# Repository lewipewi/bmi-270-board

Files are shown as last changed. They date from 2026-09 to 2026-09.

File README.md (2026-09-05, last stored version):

# bmi-270 board

Compact wireless 6-axis motion sensor board. Single-cell LiPo or USB powered,
with USB-serial for flashing and debug. Part of a larger project aimed at playing fighting games using the body.

## Hardware

| Part | Function |
|---|---|
| ESP32-C3-MINI-1-N4 | RISC-V MCU, 4 MB flash, Wi-Fi + BLE |
| BMI270 | 6-axis IMU (accel + gyro), I²C @ 0x68 |
| AP2112K-3.3 | 600 mA LDO |
| CH343P | USB-serial bridge |
| SS-12D00-G3 | SPDT slide switch — selects VBAT or VBUS as LDO input |
| JST-PH 2-pin | Battery input (no onboard charger) |

2-layer, ~40 × 42 mm. Module antenna overhangs the board edge.

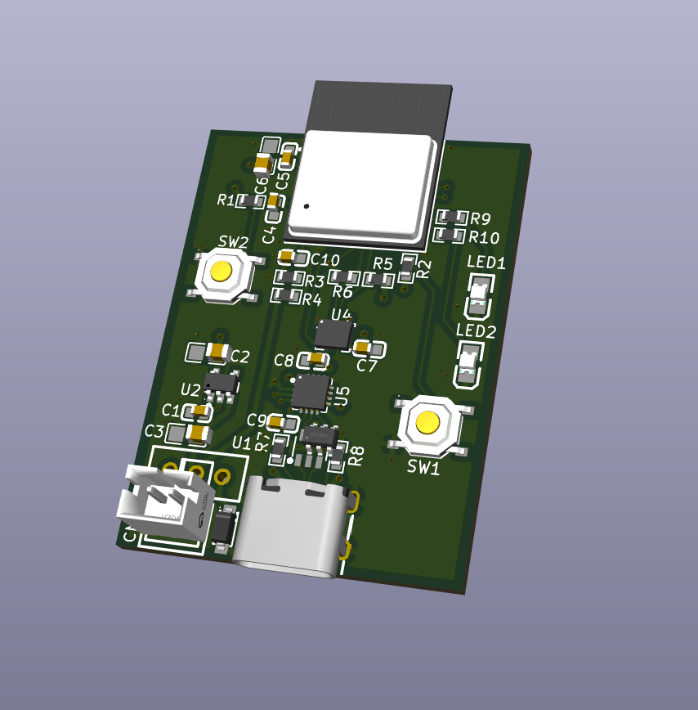
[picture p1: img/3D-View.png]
3D View

*3D View*

## Notes

- **No auto-reset.** CH343P DTR/RTS are unconnected. To flash: hold SW1, tap SW2,
  release SW1.
- **No native USB.** IO18/IO19 are used for LEDs, so USB-CDC and USB-JTAG are
  unavailable. All flashing and console goes through the CH343P.
- **No charger.** Cells must be charged externally. LDO dropout puts the practical
  low-battery cutoff around 3.6 V.
- **No reverse-polarity protection** on the battery connector. Verify cell polarity
  against CN1 (pin 1 = +) before connecting.

## Status

Board 1 assembled and under test.

- [x] Pre-power continuity checks
- [x] 3.3 V rail up
- [x] USB enumerates (CH343P)
- [ ] ROM boot log
- [ ] Flash / firmware
- [ ] IMU bring-up

### Rework log (board 1)

- One USB-C CC pin had a cold joint — board only powered with the cable in one
  orientation. Reflow CC1/CC2.
- D2 not conducting; 3.3 V rail dead until reworked.

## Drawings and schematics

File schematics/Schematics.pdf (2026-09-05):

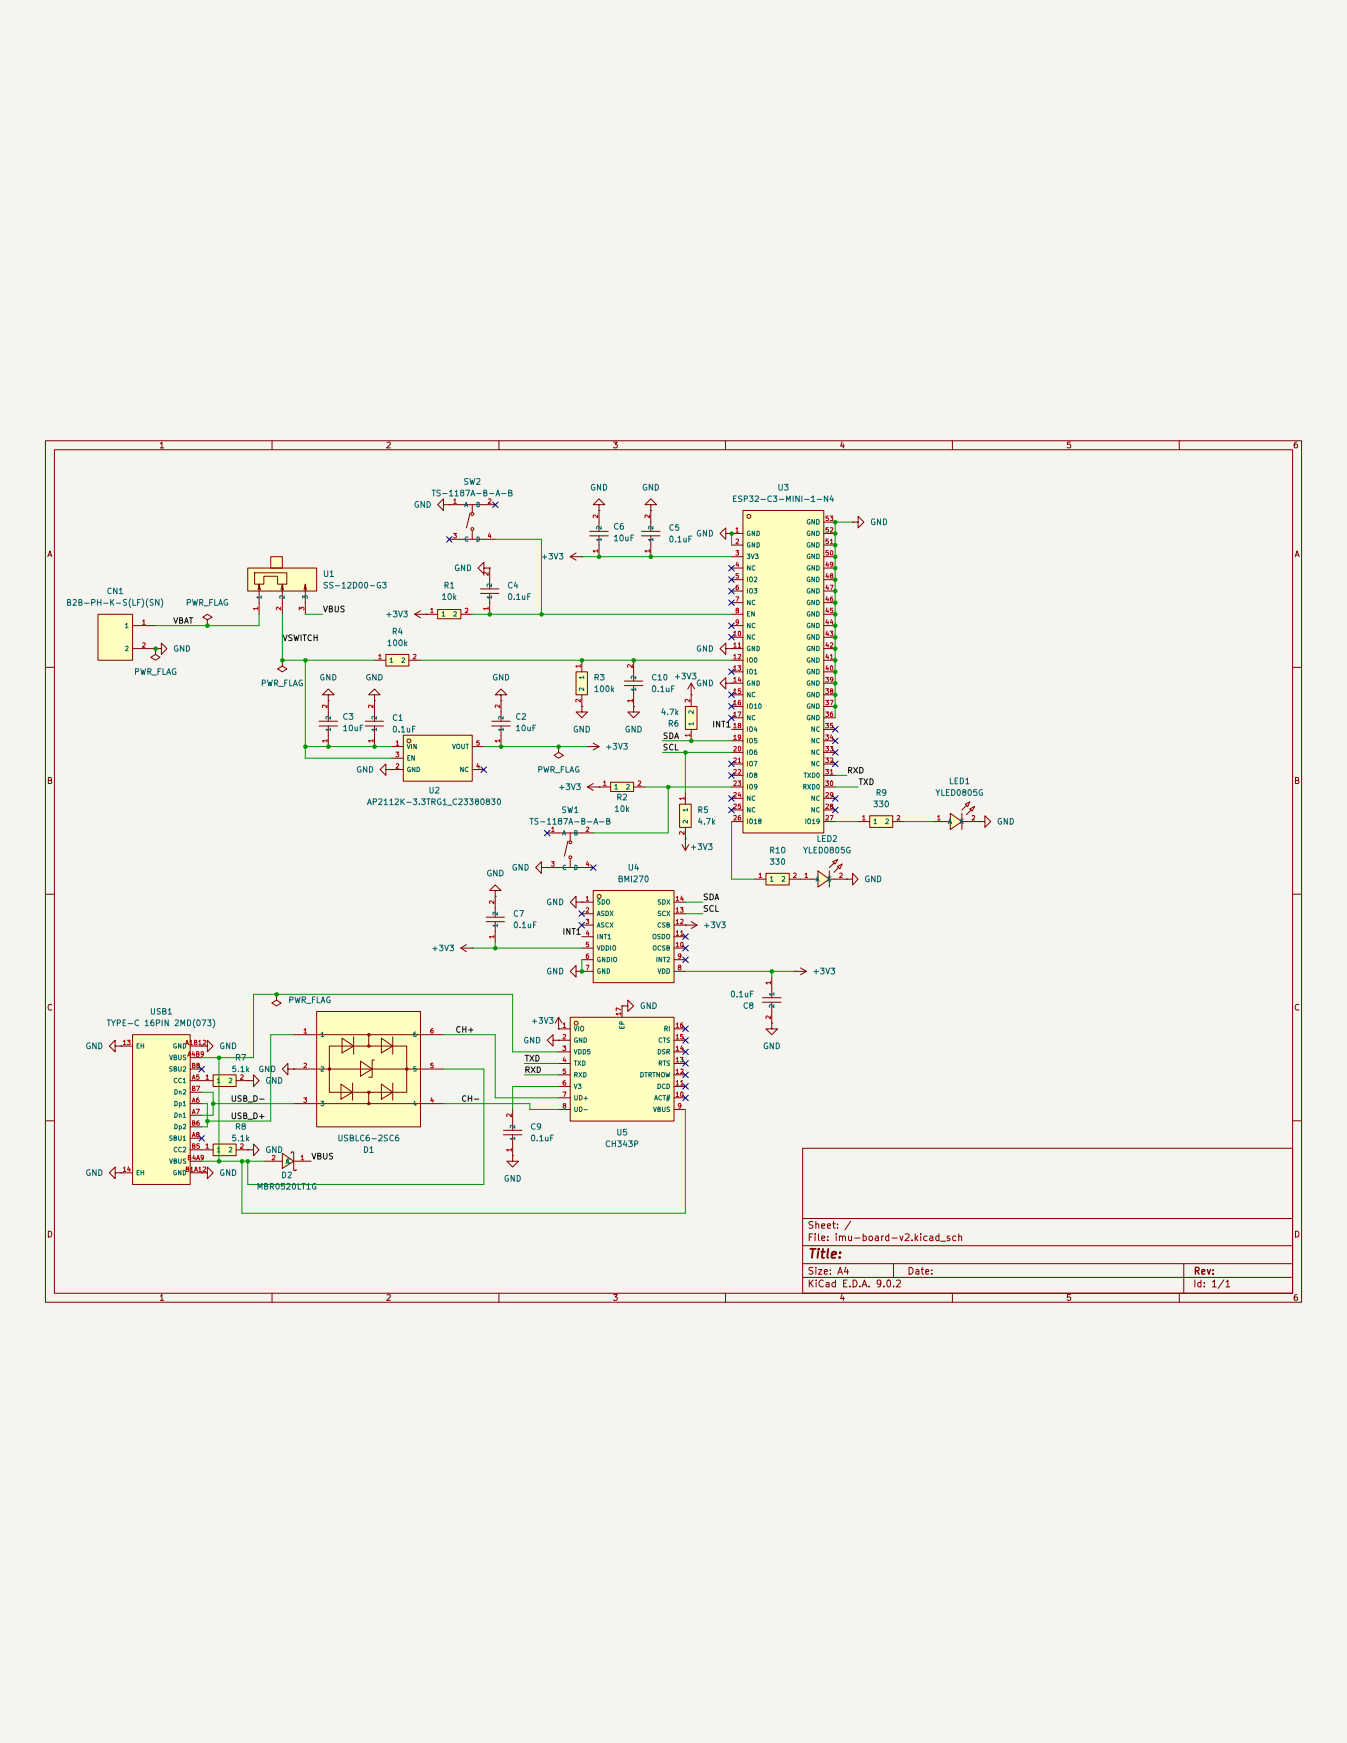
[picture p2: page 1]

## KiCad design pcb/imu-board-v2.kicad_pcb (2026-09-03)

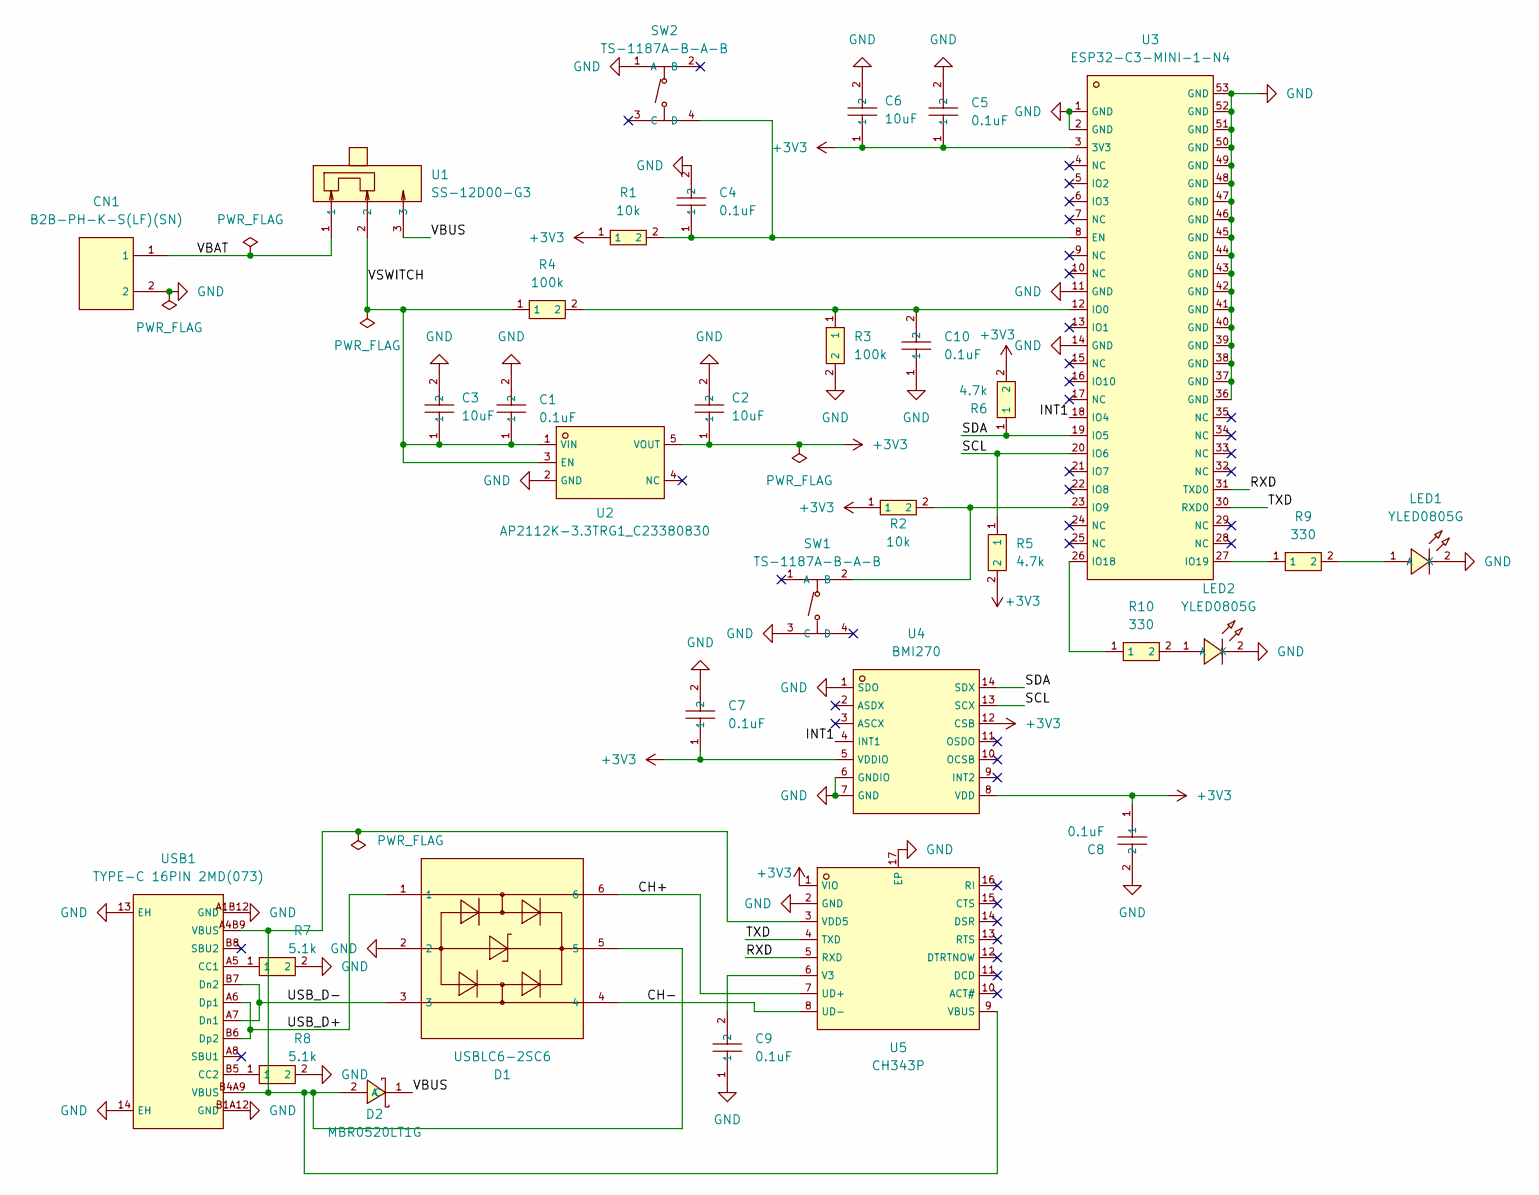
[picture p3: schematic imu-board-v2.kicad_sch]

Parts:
C1, C4, C5, C7, C8, C9, C10: 0.1uF; C1591_C0603; LCSC C1591
C2, C3, C6: 10uF; C318691_C0805; LCSC C318691
CN1: B2B-PH-K-S(LF)(SN); C131337_CONN-TH_B2B-PH-K-S; LCSC C131337
D1: USBLC6-2SC6; C7519_SOT-23-6_L2_9-W1_6-P0_95-LS2_8-BL; LCSC C7519
D2: MBR0520LT1G; C23848_SOD-123_L2_8-W1_8-LS3_7-RD; LCSC C23848
LED1, LED2: YLED0805G; C25170728_LED0805-FD-GREEN; LCSC C25170728
R1, R2: 10k; C95204_R0603; LCSC C95204
R3, R4: 100k; C2906980_R0603; LCSC C2906980
R5, R6: 4.7k; C2907034_R0603; LCSC C2907034
R7, R8: 5.1k; C2907044_R0603; LCSC C2907044
R9, R10: 330; C2933198_R0603; LCSC C2933198
SW1, SW2: TS-1187A-B-A-B; C318884_SW-SMD_4P-L5_1-W5_1-P3_70-LS6_5-TL_H1_5; LCSC C318884
U1: SS-12D00-G3; C22355741_SW-TH_3P-L8_8-W3_9-P2_50_SS12D00G3; LCSC C22355741
U2: AP2112K-3.3TRG1_C23380830; C23380830_SOT-23-5_L2_9-W1_6-P0_95-LS2_8-BR; LCSC C23380830
U3: ESP32-C3-MINI-1-N4; C2838502_WIFIM-SMD_ESP32-C3-MINI-1; LCSC C2838502
U4: BMI270; C2836813_LGA-14_L3_0-W2_5-P0_50-BR; LCSC C2836813
U5: CH343P; C2846043_TQFN-16_L3_0-W3_0-P0_50-BL-EP1_7; LCSC C2846043
USB1: TYPE-C 16PIN 2MD(073); C2765186_USB-C-SMD_TYPE-C-16PIN-2MD-073; LCSC C2765186

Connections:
+3V3: C2.1, C5.1, C6.1, C7.1, C8.1, R1.1, R2.1, R5.2, R6.2, U2.5 (VOUT), U3.3 (3V3), U4.5 (VDDIO), U4.8 (VDD), U4.12 (CSB), U5.1 (VIO)
/CH+: D1.6, U5.7 (UD+)
/CH-: D1.4, U5.8 (UD-)
/INT1: U3.18 (IO4), U4.4 (INT1)
/RXD: U3.31 (TXD0), U5.5 (RXD)
/SCL: R5.1, U3.20 (IO6), U4.13 (SCX)
/SDA: R6.1, U3.19 (IO5), U4.14 (SDX)
/TXD: U3.30 (RXD0), U5.4 (TXD)
/USB_D+: D1.1, USB1.A6 (Dp1), USB1.B6 (Dp2)
/USB_D-: D1.3, USB1.A7 (Dn1), USB1.B7 (Dn2)
/VBAT: CN1.1, U1.1
/VBUS: D2.1 (C), U1.3
/VSWITCH: C1.1, C3.1, R4.1, U1.2, U2.1 (VIN), U2.3 (EN)
GND: C1.2, C2.2, C3.2, C4.2, C5.2, C6.2, C7.2, C8.2, C9.1, C10.1, CN1.2, D1.2, LED1.2 (K), LED2.2 (K), R3.2, R7.2, R8.2, SW1.3 (C), SW2.1 (A), U2.2 (GND), U3.1 (GND), U3.2 (GND), U3.11 (GND), U3.14 (GND), U3.36 (GND), U3.37 (GND), U3.38 (GND), U3.39 (GND), U3.40 (GND), U3.41 (GND), U3.42 (GND), U3.43 (GND), U3.44 (GND), U3.45 (GND), U3.46 (GND), U3.47 (GND), U3.48 (GND), U3.49 (GND), U3.50 (GND), U3.51 (GND), U3.52 (GND), U3.53 (GND), U4.1 (SDO), U4.6 (GNDIO), U4.7 (GND), U5.2 (GND), U5.17 (EP), USB1.13 (EH), USB1.14 (EH), USB1.A1B12 (GND), USB1.B1A12 (GND)
unnamed: D1.5, D2.2 (A), U5.3 (VDD5), U5.9 (VBUS), USB1.A4B9 (VBUS), USB1.B4A9 (VBUS)
unnamed: LED1.1 (A), R9.2
unnamed: LED2.1 (A), R10.2
unnamed: R2.2, SW1.2 (B), U3.23 (IO9)
unnamed: C4.1, R1.2, SW2.4 (D), U3.8 (EN)
unnamed: C10.2, R3.1, R4.2, U3.12 (IO0)
unnamed: R10.1, U3.26 (IO18)
unnamed: R9.1, U3.27 (IO19)
unnamed: C9.2, U5.6 (V3)
unnamed: R7.1, USB1.A5 (CC1)
unnamed: R8.1, USB1.B5 (CC2)

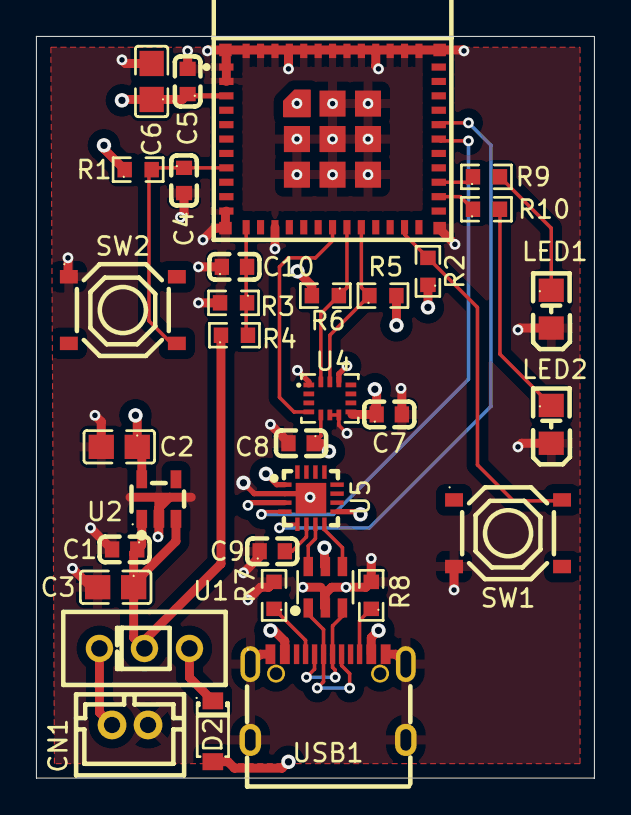
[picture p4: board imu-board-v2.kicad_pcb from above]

Board: 4 copper layers, 31.0 x 41.2 mm, 33 parts (0 on the bottom side), 25 nets.

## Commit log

2026-09-03 initial comm
    [imu-board-v2.kicad_pcb, imu-board-v2.kicad_sch]
2026-09-05 update repo structure
    [imu-board-v2.kicad_pcb, imu-board-v2.kicad_sch]
